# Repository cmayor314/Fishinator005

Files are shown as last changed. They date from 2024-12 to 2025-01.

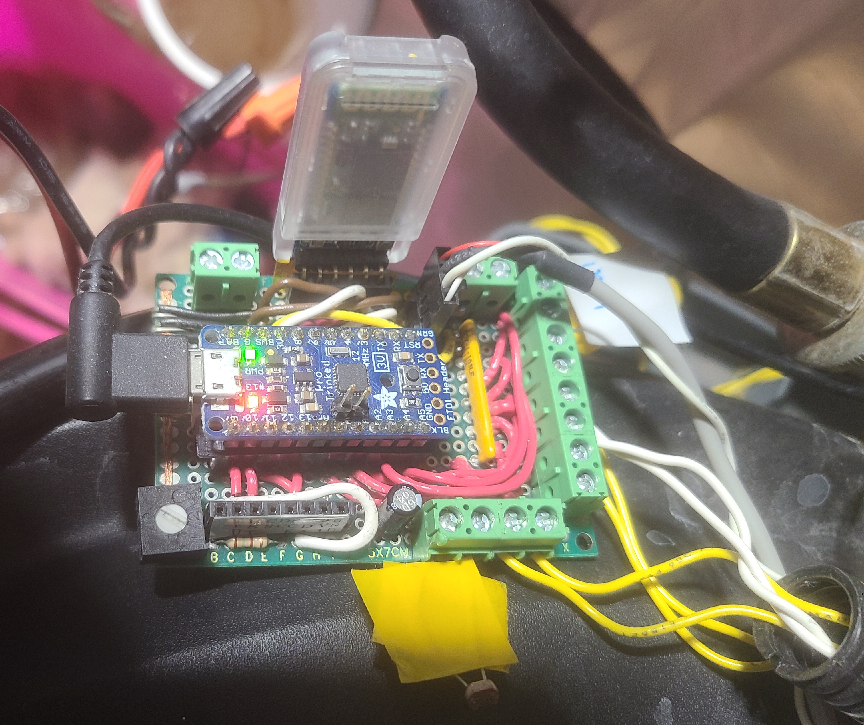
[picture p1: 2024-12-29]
RemoteSense/Remote Sense Cluster Prototype.jpg

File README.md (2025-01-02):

# Fishinator005
Fishinator005 is an **Aquaponic** system.  It is for growing both plants and fish together in a enclosed space
for the purposes of food.

## Aquaponics

Aquaponics is conservative of water; the only significant water loss is due to evaporation.
Two crops are fed for the price of one: you feed the fish and ammonia from their gills is plant food.

## What's here

The current working system is here, but still being filled in.
The documentation will take a long time.

The software/hardware includes a:

  - remote sense cluster
  
  - basic *local-to-Fishinator* control system running directly on Raspberry Pi + some hardware
  
  - basic RESTful interface on Raspberry Pi for control by Supervisor Flows
  
  - Supervisor system Control and Analysis on a remote machine with more computing power available
  
  - web-based UI

## Components:

### Supervisor 
- Control and analysis from remote machine with better computational ability via node-red and node.js

  ui_Control Fishinator
ui_Fishinator Live Graphs
ui_Fishinator Services

### FishinatorPi 
- currently Raspberry-pi implmentation of Fishinator direct control via node-red and node.js

  ui_Fishinator Dashboard

### RemoteSense 
- Atmel Mega328p implementation of reading local sensors, sent directly to Fishinator
			-KiCAD schematic files (schematic complete, placement and routing not started)
			-arduino-interface code
  
Remote Sense Cluster Prototype-small

RemoteSense schematic

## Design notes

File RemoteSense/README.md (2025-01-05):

This directory contains the **Remote Sense Cluster** for the fishinator.

This Sense Cluster is "remote" in the sense that it may be placed anywhere (within bluetooth range) with respect to the FishinatorPi (which controls the Fishinator), it is not connected by wire.  The Sense Cluster *must* be reasonably attached to the Fishinator, the system for which it senses.

The Fishinator uses this remote sense cluster to get data about light levels, temperatures, and a water-depth measurement.  Also available are voltage levels from the remote sense cluster circuit.

Via bluetooth serial, the remote sense cluster sends its data to the FishinatorPi device.

This directory includes:

  - the arduino-interface code (C/C++) for the ATMEL 328p microcontroller.
  - A subdirectory holds the (current state of) the KiCAD files for manufacturing a remote sense cluster printed circuit board.  

The KiCAD design is based on the prototype-board impementation with the Fishinator.

RemoteSense schematic

Remote Sense Cluster Prototype-small

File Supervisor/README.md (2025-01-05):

This directory is the project directory for the
**node-red** implemention of Supervisory (indirect)
control over the Fishinator Raspberry Pi direct control.

The FishinatorPi direct control (on the Raspberry Pi) does **not**
need this Supervisor to function properly. The FishinatorPi direct
control can independently operate the Fishinator. 

Because the mathematics used for signal analysis consume
heavier computation, these flows are meant to run on a 
computer with considerably more computational power than a 
Raspberry Pi.

If you have a fast Raspberry Pi from the future, the 
Supervisor code and the FishinatorPi code could run on 
the same system, but you would need to make some tweaks
(mostly with respect to IP addresses, which ports are used, etc)

The programming interface is on localhost:1880,
and the UI interface is on localhost:1880/ui

ui_Fishinator Live Graphs

ui_Fishinator Analysis

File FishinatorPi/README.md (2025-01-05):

This directory is the project directory for the
**node-red** implemention of direct control over the
Fishinator motors, sensors, and devices.

The implementation is based around using a Raspberry Pi
as the hardware with RaspbianOS installed.

The programming interface is on localhost:1880,
and the UI interface is on localhost:1880/ui

There is some currently un-documented electronic 
hardware between the Raspberry Pi and the Fishinator
actuators, real-time clock, LED bargraph, and OLED screen.

ui_Fishinator Dashboard

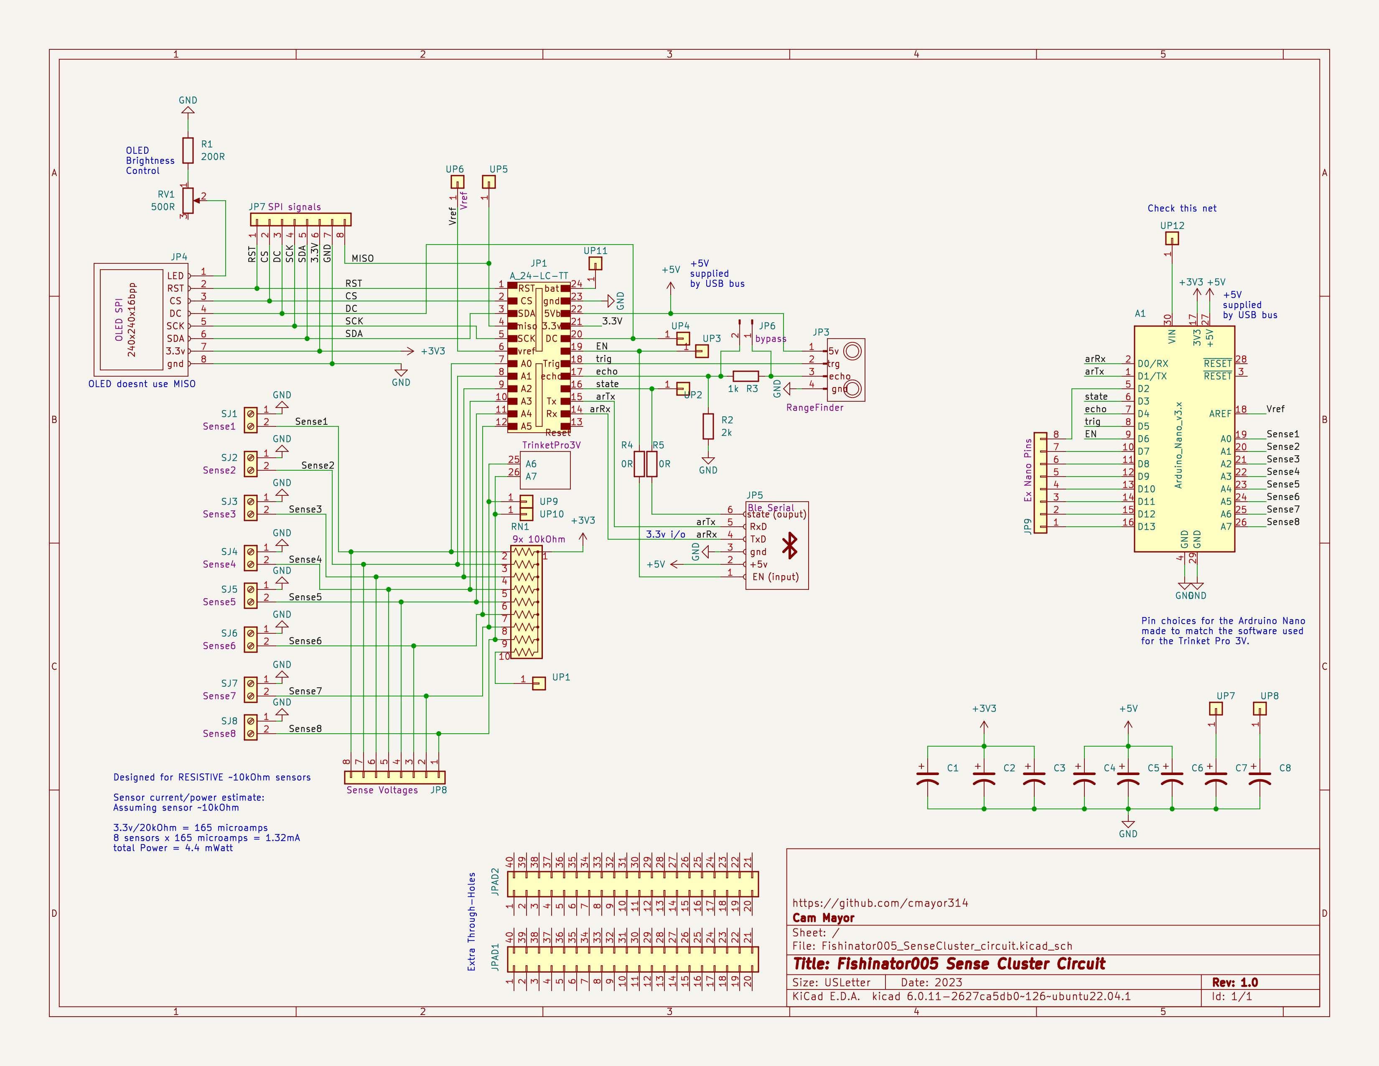
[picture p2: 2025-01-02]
RemoteSense/KiCAD/RemoteSense schematic.png

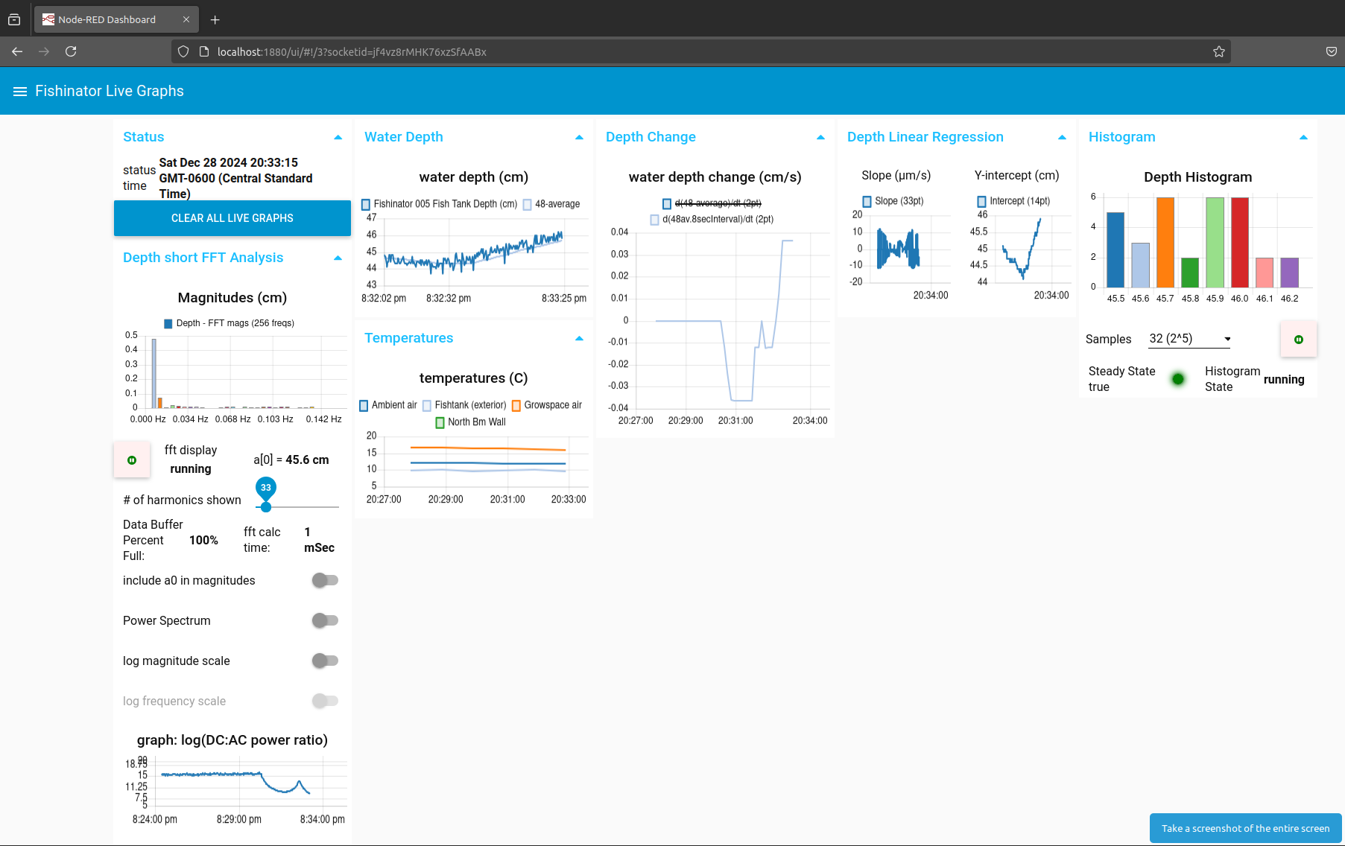
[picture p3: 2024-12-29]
Supervisor/screencaps/ui_Fishinator Live Graphs.png

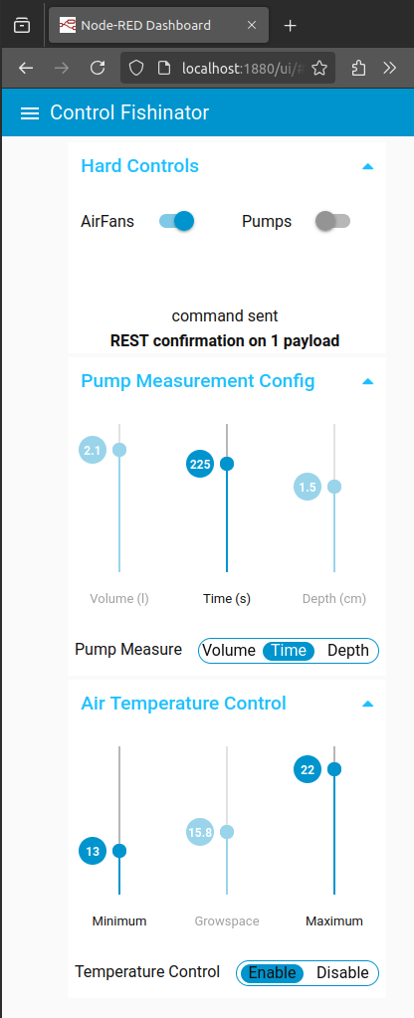
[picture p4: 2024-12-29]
Supervisor/screencaps/ui_Control Fishinator.png

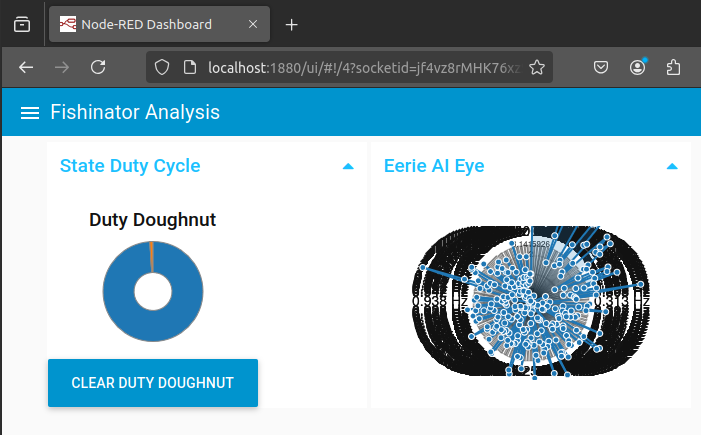
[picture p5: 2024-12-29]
Supervisor/screencaps/ui_Fishinator Analysis.png

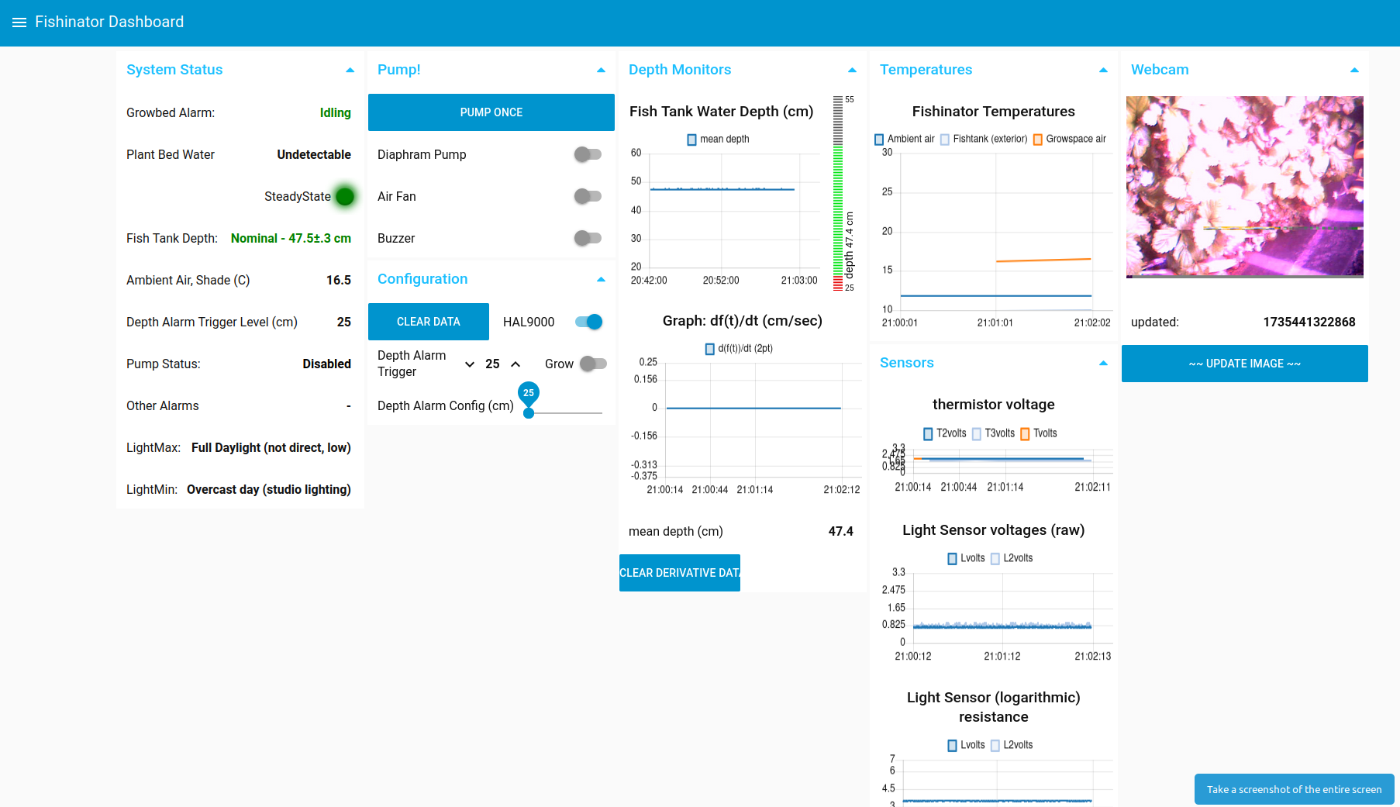
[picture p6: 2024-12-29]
FishinatorPi/screencaps/ui_Fishinator Dashboard.png

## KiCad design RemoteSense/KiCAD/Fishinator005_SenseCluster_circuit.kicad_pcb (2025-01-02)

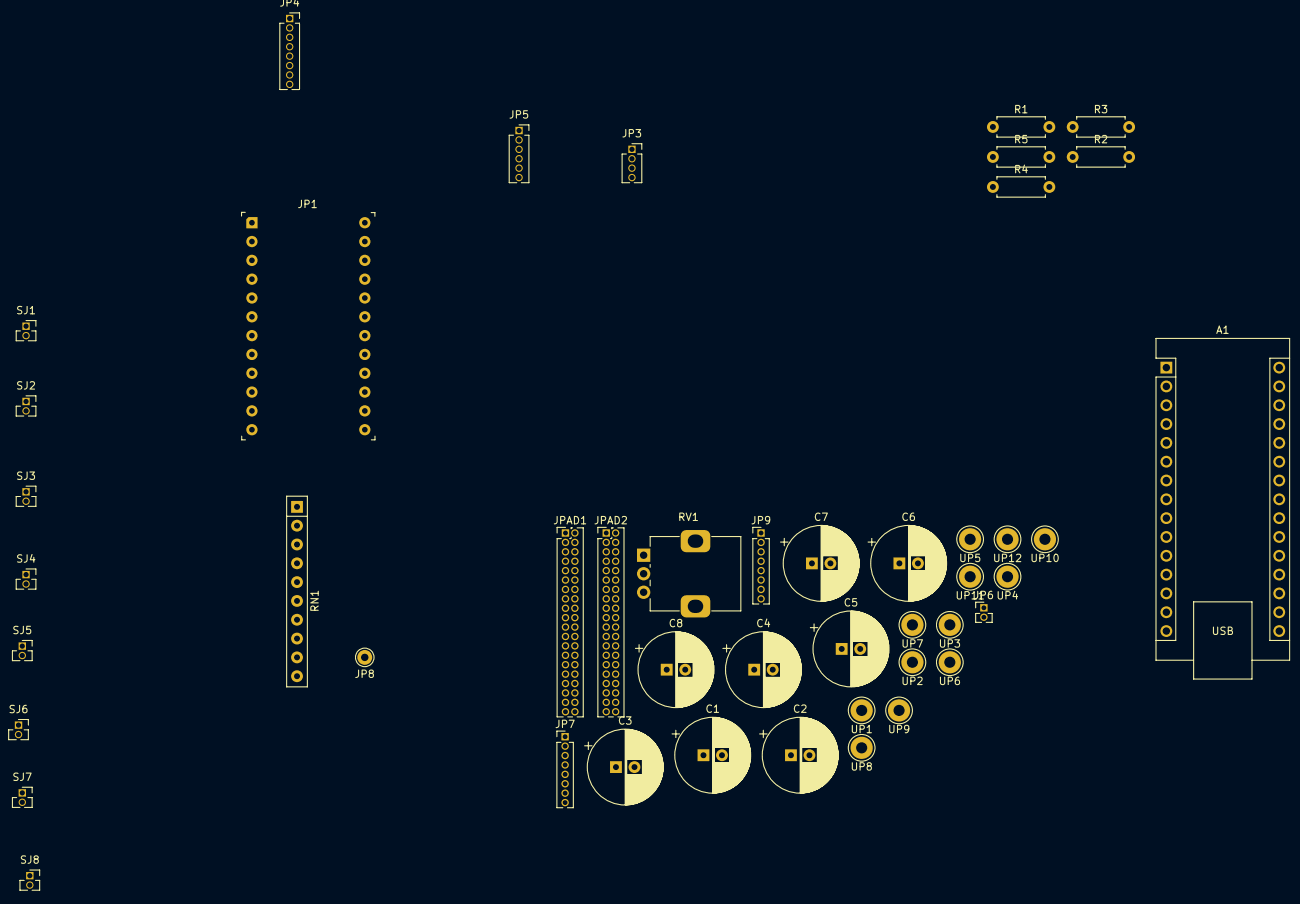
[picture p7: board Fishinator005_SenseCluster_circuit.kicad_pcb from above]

Board: 2 copper layers, 46 parts (0 on the bottom side), 42 nets, no tracks yet.

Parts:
A1: Arduino_Nano_v3.x; Arduino_Nano
C1, C2, C3, C4, C5, C6, C7, C8: C_Polarized_US; CP_Radial_D10.0mm_P2.50mm
JP1: A_24-LC-TT; Socket_DIP-24_15.24mm_Conn
JP3: Conn_01x04_Male; PinSocket_1x04_P1.27mm_Vertical
JP4: Conn_01x08_Female; PinSocket_1x08_P1.27mm_Vertical
JP5: Conn_01x06_Female; PinSocket_1x06_P1.27mm_Vertical
JP6: Conn_01x02_Male; PinHeader_1x02_P1.27mm_Vertical
JP7, JP9: Conn_01x08; PinHeader_1x08_P1.27mm_Vertical
JP8: Conn_01x08; Pin_D1.0mm_L10.0mm
JPAD1, JPAD2: Conn_02x20_Counter_Clockwise; PinHeader_2x20_P1.27mm_Vertical
R1: 200R; R_Axial_DIN0207_L6.3mm_D2.5mm_P7.62mm_Horizontal
R2: 2k; R_Axial_DIN0207_L6.3mm_D2.5mm_P7.62mm_Horizontal
R3: 1k; R_Axial_DIN0207_L6.3mm_D2.5mm_P7.62mm_Horizontal
R4, R5: 0R; R_Axial_DIN0207_L6.3mm_D2.5mm_P7.62mm_Horizontal
RN1: R_Network09_US; R_Array_SIP10
RV1: 500R; Potentiometer_Alps_RK09K_Single_Vertical
SJ1, SJ2, SJ3, SJ4, SJ5, SJ6, SJ7, SJ8: Screw_Terminal_01x02; PinSocket_1x02_P1.27mm_Vertical
UP1, UP2, UP3, UP4, UP5, UP6, UP7, UP8, UP9, UP10, UP11, UP12: Conn_01x01; Pin_D1.3mm_L11.0mm_LooseFit

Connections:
+3V3: A1.17 (3V3), C1.1, C2.1, C3.1, JP1.21, JP4.7, JP7.6, RN1.1 (common)
+5V: A1.27 (+5V), C4.1, C5.1, C6.1, JP1.22, JP3.1, JP5.2
/CS: JP1.2, JP4.3, JP7.2
/DC: JP1.20, JP4.4, JP7.3, UP4.1
/EN: A1.9 (D6), JP1.19, R4.1, UP3.1
/MISO: JP1.4, JP7.8, UP5.1
/RST: JP1.1, JP4.2, JP7.1
/SCK: JP1.5, JP4.5, JP7.4
/SDA: JP1.3, JP4.6, JP7.5
/Sense1: A1.19 (A0), JP1.7, RN1.2 (R1), SJ1.2
/Sense2: A1.20 (A1), JP1.8, RN1.3 (R2), SJ2.2
/Sense3: A1.21 (A2), JP1.9, RN1.4 (R3), SJ3.2
/Sense4: A1.22 (A3), JP1.10, RN1.5 (R4), SJ4.2
/Sense5: A1.23 (A4), JP1.11, RN1.6 (R5), SJ5.2
/Sense6: A1.24 (A5), JP1.12, RN1.7 (R6), SJ6.2
/Sense7: A1.25 (A6), RN1.8 (R7), SJ7.2, UP9.1
/Sense8: A1.26 (A7), JP8.1, RN1.9 (R8), SJ8.2, UP10.1
/Vref: A1.18 (AREF), JP1.6, UP6.1
/arRx: A1.2 (D0/RX), JP1.14, JP5.4
/arTx: A1.1 (D1/TX), JP1.15, JP5.5
/echo: A1.7 (D4), JP1.17, JP6.2, R2.1, R3.1
/state: A1.6 (D3), JP1.16, R5.1, UP2.1
/trig: A1.8 (D5), JP1.18, JP3.2
GND: A1.4 (GND), A1.29 (GND), C1.2, C2.2, C3.2, C4.2, C5.2, C6.2, C7.2, C8.2, JP1.23, JP3.4, JP4.8, JP5.3, JP7.7, R1.1, R2.2, SJ1.1, SJ2.1, SJ3.1, SJ4.1, SJ5.1, SJ6.1, SJ7.1, SJ8.1
unnamed: A1.5 (D2), JP9.8
unnamed: A1.10 (D7), JP9.7
unnamed: A1.11 (D8), JP9.6
unnamed: A1.12 (D9), JP9.5
unnamed: A1.13 (D10), JP9.4
unnamed: A1.14 (D11), JP9.3
unnamed: A1.15 (D12), JP9.2
unnamed: A1.16 (D13), JP9.1
unnamed: A1.30 (VIN), UP12.1
unnamed: C7.1, UP7.1
unnamed: C8.1, UP8.1
unnamed: JP1.24, UP11.1
unnamed: JP3.3, JP6.1, R3.2
unnamed: JP4.1, RV1.2
unnamed: JP5.1, R4.2
unnamed: JP5.6, R5.2
unnamed: R1.2, RV1.1
unnamed: RN1.10 (R9), UP1.1

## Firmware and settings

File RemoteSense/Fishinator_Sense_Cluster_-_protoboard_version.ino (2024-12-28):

//Fishinator 2020 - Remote Sense Cluster

//This microcontroller code should be paired with the sister-code, 
//running on node-red on the other side of the bluetooth connection
//controlling the Fishinator 2020.

//TFT code based on sample code Written by Limor Fried/Ladyada for Adafruit Industries.
//(redistribution text is found at the bottom of file for my clarity)

#include <Adafruit_GFX.h>    // Core graphics library
#include <Adafruit_ST7789.h> // Hardware-specific library for ST7789
#include <SPI.h>
#include <stdio.h>

#include "Ultrasonic.h"  //hc-sr04 ultrasonic module library

#define myTrigger (5)
#define myEcho  (4)

Ultrasonic myPing(myTrigger, myEcho);

// For the breakout board, you can use any 2 or 3 pins.
// These pins will also work for the 1.8" TFT shield.
#define TFT_CS        10
#define TFT_RST        9 // Or set to -1 and connect to Arduino RESET pin
#define TFT_DC         8

// For 1.3", 1.54", and 2.0" TFT with ST7789:
Adafruit_ST7789 tft = Adafruit_ST7789(TFT_CS, TFT_DC, TFT_RST);

//thermistor inputs (analog input pins)
#define TMPSNS1 A5  //ambient
#define TMPSNS2 A4  //tank
#define TMPSNS3 A3 //growspace

//10k combined with 1k-300k cds light sensor
#define LIGHTSNS1 A0  //ambient (above tank below growspace)
#define LIGHTSNS2 A1  //growspace  (might want to change this to a 1k for better high-light sense)

//pins to watch system voltages (from resistive bridge to power 3.3v/5v)
#define VOLTWATCH33 A6  //1k pulled high, 10k pulled low.  sample 3.3v(10/11) voltage
#define VOLTWATCH5  A7  //30k from 5v to gnd, tap at 20k for 5v*(2/3)=3.3v

#define UNDEFINEDANALOGPIN  A2  //as yet unused

#define MAXBLITDIM (127)
boolean blit[MAXBLITDIM * MAXBLITDIM * 2];

//lasttime for detecting the period for 1 cycle of loop()
uint16_t lasttime = 0;

//clear TFT by default, but any 8 bit value OK
void clear_blit(uint8_t num, uint8_t value = false) {
  //tft.fillScreen(ST77XX_BLACK);
  tft.setTextSize(3);
  drawtext("starting...", ST77XX_WHITE);
  delay(1500);

  switch (num) {
    //clear first bank
    case 0: //memset(blit,value, MAXBLITDIM*MAXBLITDIM);
      break;
    //clear second bank
    case 1: memset(blit + MAXBLITDIM * MAXBLITDIM, value, MAXBLITDIM * MAXBLITDIM);
      break;
    default: break; //do nothing
  }//*/
}


void setup(void) {
  pinMode(0, INPUT);
  pinMode(1, OUTPUT); //which are the rx/tx pins
  lasttime = millis();
  
  Serial.begin(9600);  while (!Serial) {}    ;  //wait for it
  
  //setup bluetooth
  Serial.println(F("AT+DEFAULT")); //soft reset
  delay(500);
  /*
    Serial.println("AT+PIN4444");
    delay(500);
    Serial.println("AT+BAUD3");
    delay(500);
    Serial.println("AT+NAMEfishinator");
    delay(500);
    Serial.println("AT+START");*/

  //use this initializer (uncomment) if using a 1.3" or 1.54" 240x240 TFT:
  tft.init(240, 240);           // Init ST7789 240x240

  clear_blit(false);
  tft.fillScreen(ST77XX_BLACK);

  pinMode(TMPSNS1, INPUT );
  pinMode(TMPSNS2, INPUT );
  pinMode(TMPSNS3, INPUT );
  pinMode(LIGHTSNS1, INPUT );
  //pinMode(LIGHTSNS2, INPUT );
  pinMode(VOLTWATCH33, INPUT );
  pinMode(VOLTWATCH5, INPUT );

  drawtext("Ultrasonic/Graphics", ST77XX_WHITE);
  delay(750);
}

void drawtext(char *text, uint16_t color) {
  tft.setCursor(0, 0);
  tft.setTextSize(2);
  tft.setTextColor(color);
  tft.setTextWrap(true);
  tft.print(text);
}

/* THE FOLLOWING TWO FUNCTIONS ARE THE SAME FUNCTION!!!! */
//read the 1k - 300k CdS in series with 10k fixed resistor
//using the 3.3v supply as source.
//returns: voltage in millivolts
float readLightBridgeVoltageMV(int senseNum) { return 3300.0 * analogRead(senseNum) / 1024.0; }

//read the 10k Thermistor voltage, half bridge with 10k fixed resistor to 3.3v
float readThermistorBridgeVoltageMV(int senseNum) { return 3300.0 * analogRead(senseNum) / 1024.0; }




void loop() {
  char report[80]; //re-useable string - bigger than needed for now - watch for buffer overflows
  tft.fillScreen(ST77XX_BLACK);  //clear the TFT
  unsigned int millivolts = 0;

  uint16_t nowtime = millis();
  uint16_t looptime = nowtime - lasttime; 
  sprintf(report, "SenseClusterXLoopTime,%u,ms\r\n", looptime  );
  Serial.print(report);  //send out  bluetooth serial port

  //Report Local Ultrasonic Distance Sensor
  //long durat = myPing.Timing();//get a new ultrasonic reading, in milliseconds
  //float fdist_cm = durat / 58.3; //58.3 ms/cm is 1/speedofsound * 2 traversals (1 each way)
  float fdist_cm = myPing.read(CM);

  tft.setCursor(0, 125);
  // out-of-range values bad
  if (fdist_cm < 400) {
    //there's some legacy cruft here, but whatever, just leave it.
    unsigned int decimetres = 10 * fdist_cm;
    sprintf(report, "WaterDistance,%u.%1u,cm\r\n", decimetres / 10, decimetres - 10 * (decimetres / 10) );
    tft.print(report);
    Serial.print(report);
  }
  else
  {
    Serial.print("WaterDistance,OutOfRange,cm\r\n");
    tft.print("WaterDistance,OutOfRange,cm\r\n");
  }
  tft.setCursor(0, 25);
  tft.print(fdist_cm); tft.print(F(" cm   "));


  //Report Local Thermistor Temperature Voltages
  
  //thermistor voltage, 10k@25C thermistor in series with 10k fixed resistor
  //regulated 3.3volts source voltage

  millivolts = readThermistorBridgeVoltageMV(TMPSNS1);
  sprintf(report, "Tvolts,%u.%.3u,v\r\n", millivolts / 1000, millivolts - 1000 * (millivolts / 1000)  );
  Serial.print(report);  //send out  bluetooth serial port
  
  tft.setCursor(0, 50);
  tft.print(millivolts/1000.0); tft.print(F(" volts "));
  tft.setCursor(0, 100);
  tft.print(report); //send to screen

  //this is the SECOND thermistor temperature
  millivolts = readThermistorBridgeVoltageMV(TMPSNS2);
  sprintf(report, "T2volts,%u.%.3u,v\r\n", millivolts / 1000, millivolts - 1000 * (millivolts / 1000)  );
  Serial.print(report);  //send out  bluetooth serial port
  
  //this is the THIRD thermistor temperature
  millivolts = readThermistorBridgeVoltageMV(TMPSNS3);
  sprintf(report, "T3volts,%u.%.3u,v\r\n", millivolts / 1000, millivolts - 1000 * (millivolts / 1000)  );
  Serial.print(report);  //send out  bluetooth serial port



  //Report Local Light Sensors (1k - 300k CdS in series with 10k fixed resistor)
  millivolts = readLightBridgeVoltageMV(LIGHTSNS1);
  sprintf(report, "Lvolts,%u.%.3u,v\r\n", millivolts / 1000, millivolts - 1000 * (millivolts / 1000)  );
  
  tft.setCursor(0, 150);
  tft.print(report); //send to screen   //just report this one for now.
  Serial.print(report);  //send out  bluetooth serial port

  //second  light sensor -
  millivolts = readLightBridgeVoltageMV(LIGHTSNS2);
  sprintf(report, "L2volts,%u.%.3u,v\r\n", millivolts / 1000, millivolts - 1000 * (millivolts / 1000)  );
  Serial.print(report);  //send out  bluetooth serial port


  //Report Local Power Supply/Battery/Bus Voltages
  
  //regulated 3.3 volts
  float vcc33 = 11 * 3.3 * analogRead(VOLTWATCH33) / 1024 / 10; //compensated for 10/11 resistor bridge
  millivolts = vcc33 * 1000;
  sprintf(report, "VCCvolts,%u.%.3u,v\r\n", millivolts / 1000, millivolts - 1000 * (millivolts / 1000)  );
  tft.setCursor(0, 175);
  tft.print(report); //send to screen
  Serial.print(report);  //send out  bluetooth serial port

  //USB (5v) bus voltage
  float vcc5 = 3 * 3.3 * analogRead(VOLTWATCH5) / 1024 / 2; //compensated for 2/3 resistor bridge
  millivolts = vcc5 * 1000;
  sprintf(report, "BUSvolts,%u.%.3u,v\r\n", millivolts / 1000, millivolts - 1000 * (millivolts / 1000)  );
  tft.setCursor(0, 200);
  tft.print(report); //send to screen
  Serial.print(report);  //send out  bluetooth serial port
}


//** use the stuff below here as an example, but it does nothing in this project
/*
void tftSecondsCount() {
  tft.setTextWrap(false);
  tft.fillScreen(ST77XX_BLACK);
  tft.setCursor(0, 30);
  tft.setTextColor(ST77XX_WHITE);
  tft.setTextSize(3);
  tft.println("Sketch has been");
  tft.println("running for: ");
  tft.setTextColor(ST77XX_MAGENTA);
  tft.print(millis() / 1000);
  tft.setTextColor(ST77XX_WHITE);
  tft.print(" seconds.");
  tft.setTextSize(0);
}

void printRandomBoxOnTFT() 
{
    //this continuously prints a randomly coloured box, on pixel per loop
    tft.setCursor(0, 0);
    if (92 > random(100))
      tft.drawPixel((56 + (int16_t) random(MAXBLITDIM)), (56 + (int16_t) random(MAXBLITDIM)), 0); //turn off pixel
    else
      tft.drawPixel((56 + (int16_t) random(MAXBLITDIM)), (56 + (int16_t) random(MAXBLITDIM)), (uint16_t) random(65538));
    delay(0);
}

void tftPrintTest() {
  tft.setTextWrap(false);
  tft.fillScreen(ST77XX_BLACK);
  tft.setCursor(0, 30);
  tft.setTextColor(ST77XX_RED);
  tft.setTextSize(1);
  tft.println("Hello World!");
  tft.setTextColor(ST77XX_YELLOW);
  tft.setTextSize(2);
  tft.println("Hello World!");
  tft.setTextColor(ST77XX_GREEN);
  tft.setTextSize(3);
  tft.println("Hello World!");
  tft.setTextColor(ST77XX_BLUE);
  tft.setTextSize(4);
  tft.print(1234.567);
  delay(1500);
  tft.setCursor(0, 0);
  tft.fillScreen(ST77XX_BLACK);
  tft.setTextColor(ST77XX_WHITE);
  tft.setTextSize(0);
  tft.println("Hello World!");
  tft.setTextSize(1);
  tft.setTextColor(ST77XX_GREEN);
  tft.print(p, 6);
  tft.println(" Want pi?");
  tft.println(" ");
  tft.print(8675309, HEX); // print 8,675,309 out in HEX!
  tft.println(" Print HEX!");
  tft.println(" ");

  tft.setTextColor(ST77XX_WHITE);
  tft.setTextSize(3);
  tft.println("Sketch has been");
  tft.println("running for: ");
  tft.setTextColor(ST77XX_MAGENTA);
  tft.print(millis() / 1000);
  tft.setTextColor(ST77XX_WHITE);
  tft.print(" seconds.");
  tft.setTextSize(0);
}*/

/**************************************************************************
  This is a library for several Adafruit displays based on ST77* drivers.

  Works with the Adafruit 1.8" TFT Breakout w/SD card
    ----> http://www.adafruit.com/products/358
  The 1.8" TFT shield
    ----> https://www.adafruit.com/product/802
  The 1.44" TFT breakout
    ----> https://www.adafruit.com/product/2088
  The 1.3" TFT breakout
  ----> https://www.adafruit.com/product/4313
  The 1.54" TFT breakout
    ----> https://www.adafruit.com/product/3787
  The 2.0" TFT breakout
    ----> https://www.adafruit.com/product/4311
  as well as Adafruit raw 1.8" TFT display
    ----> http://www.adafruit.com/products/618

  Check out the links above for our tutorials and wiring diagrams.
  These displays use SPI to communicate, 4 or 5 pins are required to
  interface (RST is optional).

  Adafruit invests time and resources providing this open source code,
  please support Adafruit and open-source hardware by purchasing
  products from Adafruit!

  Written by Limor Fried/Ladyada for Adafruit Industries.
  MIT license, all text above must be included in any redistribution
 **************************************************************************/

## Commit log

2024-12-28 first add of Raspberry Pi flow code
2024-12-28 Picture of Remote Sense Cluster working prototype
2024-12-29 photo of prototype
2025-01-02 upload schematic files
    [Fishinator005_SenseCluster_circuit.kicad_pcb, Fishinator005_SenseCluster_circuit.kicad_sch]
2025-01-05 Update README.md
    added image of schematic and photo of prototype version
